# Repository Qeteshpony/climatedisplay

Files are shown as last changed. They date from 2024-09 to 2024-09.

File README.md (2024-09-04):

# Climate Display



3D Render

[Hardware Documentation](https://qeteshpony.github.io/climatedisplay)

Complete overhaul of one of my earlier electronics projects! A display that is running here for years, back then made completely with THT components on a crude pcb. It shows the temperature and dew point for the room and outdoor sensors. 

I learned a lot about pcb design since then and was not happy with the look of the old device so I remade the whole device in a way that keeps the general look but a lot more fancy, moving everything but the display elements to the back of the board, adding a 3d-printed frame, replacing the barrel connector with USB-C and many more little things. 

The old version also had the digits of the displays backwards which didnt matter when I wrote the arduino script to run it. But now I want to use ESP-Home so they have to be wired correctly ;)

Every other dual-7-segment module is upside down so the decimal dot on the last digit in each row can be used as a ° symbol.

The original project was documented on my blog: https://electronics.qetesh.de/climate-display/

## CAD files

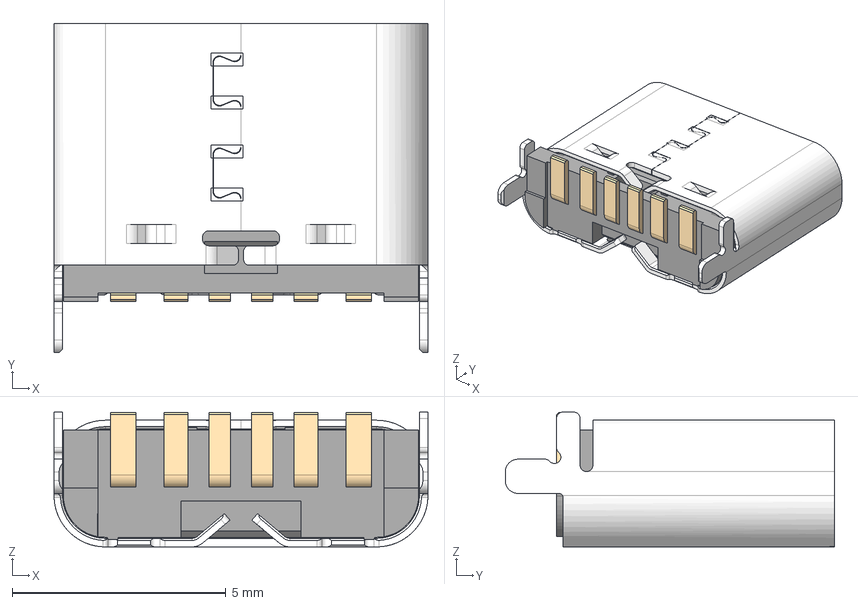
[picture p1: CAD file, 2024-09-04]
pcb/USB4130-GF-A_REVA/USB4130-GF-C.stp
8.74 x 7.70 x 3.15 mm

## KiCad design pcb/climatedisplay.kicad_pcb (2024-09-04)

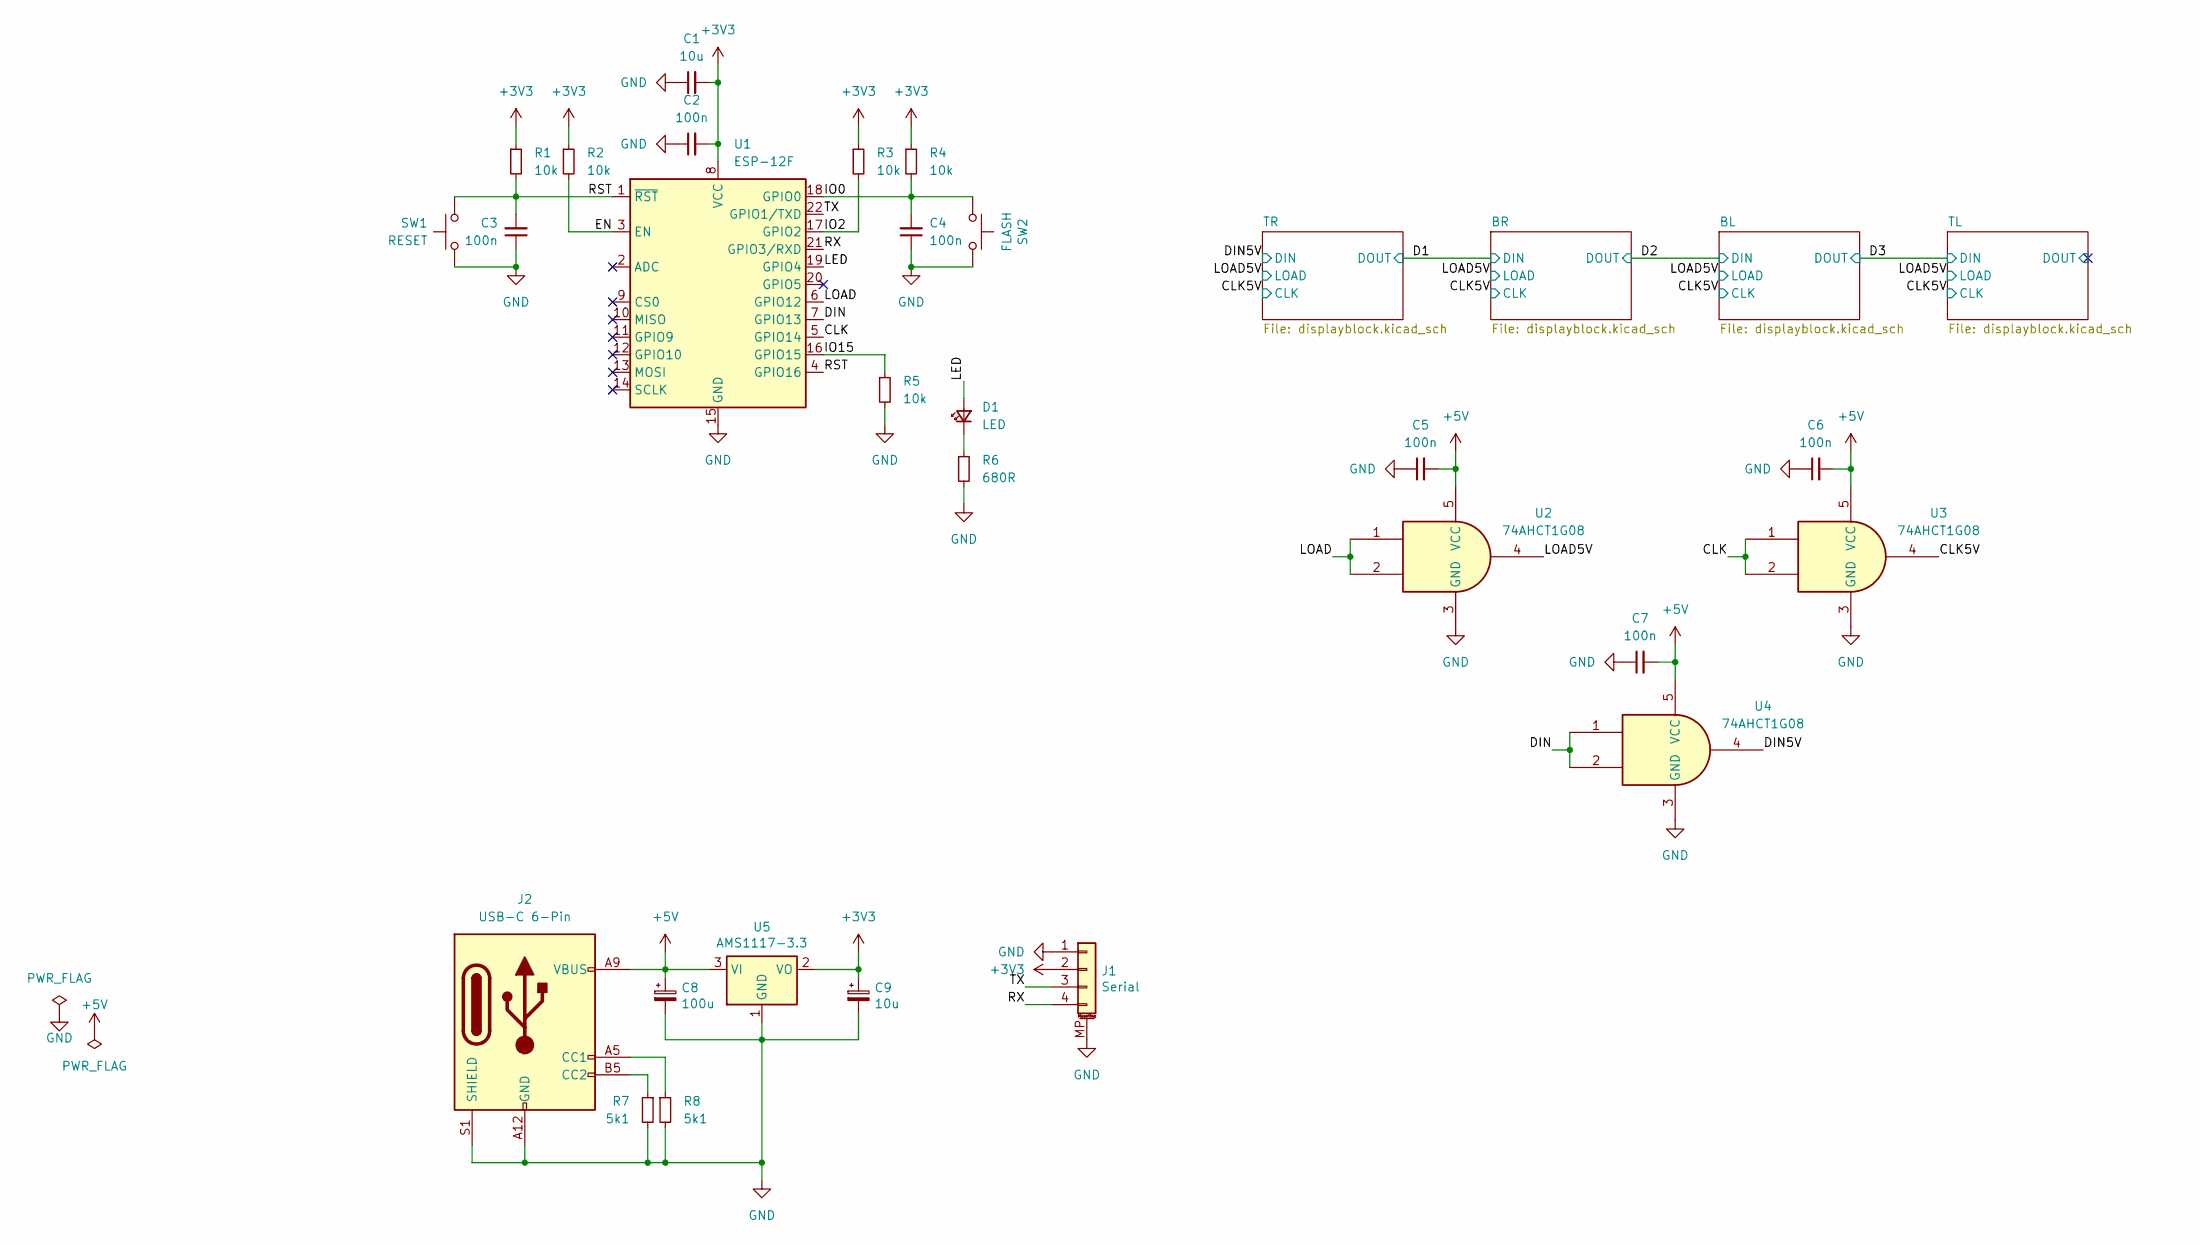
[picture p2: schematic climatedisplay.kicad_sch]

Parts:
C1: 10u; C_0402_1005Metric; LCSC C15525
C2, C3, C4, C5, C6, C7: 100n; C_0402_1005Metric; LCSC C1525
C8: 100u; CP_EIA-3528-21_Kemet-B; LCSC C16133
C9: 10u; CP_EIA-3216-18_Kemet-A; LCSC C7171
D1: LED; LED_0603_1608Metric; LCSC C2286
J1: Serial; JST_PH_S4B-PH-SM4-TB_1x04-1MP_P2.00mm_Horizontal
J2: USB-C 6-Pin; GCT_USB4130-GF-A_REVA
R1, R2, R3, R4, R5: 10k; R_0402_1005Metric; LCSC C25744
R6: 680R; R_0402_1005Metric; LCSC C25130
R7, R8: 5k1; R_0402_1005Metric; LCSC C25905
SW1: RESET; SW_Push_1P1T_XKB_TS-1187A; LCSC C318884
SW2: FLASH; SW_Push_1P1T_XKB_TS-1187A; LCSC C318884
U1: ESP-12F; ESP-12E
U2, U3, U4: 74AHCT1G08; SOT-353_SC-70-5; LCSC C455047
U5: AMS1117-3.3; SOT-223-3_TabPin2; LCSC C6186

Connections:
+3V3: C1.2, C2.2, C9.1, J1.2, R1.1, R2.1, R3.1, R4.1, U1.8 (VCC), U5.2 (VO)
+5V: C5.2, C6.2, C7.2, C8.1, J2.A9 (VBUS), J2.B9 (VBUS), U2.5 (VCC), U3.5 (VCC), U4.5 (VCC), U5.3 (VI); also elsewhere on the board
/CLK: U1.5 (GPIO14), U3.1, U3.2
/CLK5V: U3.4; also elsewhere on the board
/DIN: U1.7 (GPIO13), U4.1, U4.2
/DIN5V: U4.4; also elsewhere on the board
/EN: R2.2, U1.3 (EN)
/IO0: C4.2, R4.2, SW2.1, U1.18 (GPIO0)
/IO2: R3.2, U1.17 (GPIO2)
/IO15: R5.1, U1.16 (GPIO15)
/LED: D1.2 (A), U1.19 (GPIO4)
/LOAD: U1.6 (GPIO12), U2.1, U2.2
/LOAD5V: U2.4; also elsewhere on the board
/RST: C3.2, R1.2, SW1.2, U1.1 (~RST), U1.4 (GPIO16)
/RX: J1.4, U1.21 (GPIO3/RXD)
/TX: J1.3, U1.22 (GPIO1/TXD)
GND: C1.1, C2.1, C3.1, C4.1, C5.1, C6.1, C7.1, C8.2, C9.2, J1.1, J1.MP (MountPin), J2.A12 (GND), J2.B12 (GND), J2.S1 (SHIELD), R5.2, R6.2, R7.2, R8.2, SW1.1, SW2.2, U1.15 (GND), U2.3 (GND), U3.3 (GND), U4.3 (GND), U5.1 (GND); also elsewhere on the board
unnamed: D1.1 (K), R6.1
unnamed: J2.A5 (CC1), R8.1
unnamed: J2.B5 (CC2), R7.1

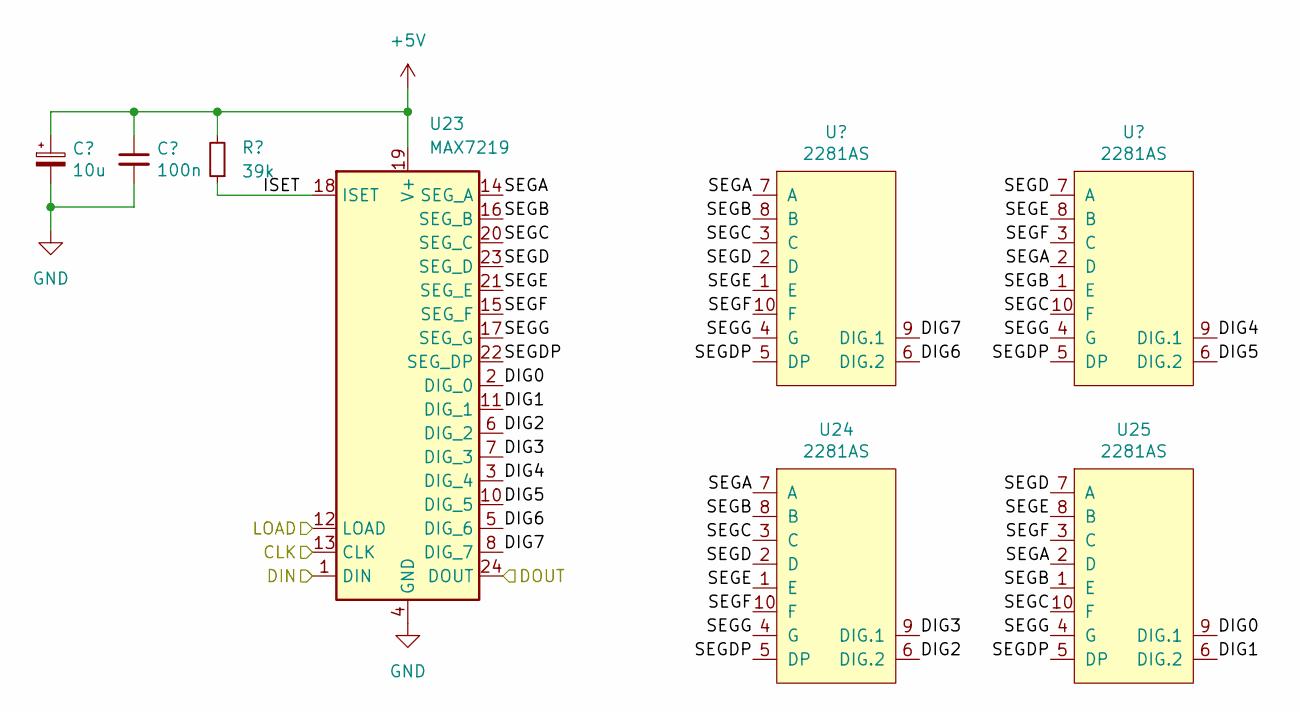
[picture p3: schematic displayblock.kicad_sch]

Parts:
C16: 10u; CP_EIA-3216-18_Kemet-A; LCSC C7171
C17: 100n; C_0402_1005Metric; LCSC C1525
R12: 39k; R_0402_1005Metric; LCSC C25783
U21, U22, U24, U25: 2281AS; 2281AS_BS
U23: MAX7219; SOP-24_7.5x15.4mm_P1.27mm; LCSC C9964

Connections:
+5V: C16.1, C17.1, R12.2, U23.19 (V+); also elsewhere on the board
/CLK5V: U23.13 (CLK); also elsewhere on the board
/D3: U23.1 (DIN); also elsewhere on the board
/LOAD5V: U23.12 (LOAD); also elsewhere on the board
/TL/DIG0: U23.2 (DIG_0), U25.9 (DIG.1)
/TL/DIG1: U23.11 (DIG_1), U25.6 (DIG.2)
/TL/DIG2: U23.6 (DIG_2), U24.6 (DIG.2)
/TL/DIG3: U23.7 (DIG_3), U24.9 (DIG.1)
/TL/DIG4: U22.9 (DIG.1), U23.3 (DIG_4)
/TL/DIG5: U22.6 (DIG.2), U23.10 (DIG_5)
/TL/DIG6: U21.6 (DIG.2), U23.5 (DIG_6)
/TL/DIG7: U21.9 (DIG.1), U23.8 (DIG_7)
/TL/DOUT: U23.24 (DOUT)
/TL/ISET: R12.1, U23.18 (ISET)
/TL/SEGA: U21.7 (A), U22.2 (D), U23.14 (SEG_A), U24.7 (A), U25.2 (D)
/TL/SEGB: U21.8 (B), U22.1 (E), U23.16 (SEG_B), U24.8 (B), U25.1 (E)
/TL/SEGC: U21.3 (C), U22.10 (F), U23.20 (SEG_C), U24.3 (C), U25.10 (F)
/TL/SEGD: U21.2 (D), U22.7 (A), U23.23 (SEG_D), U24.2 (D), U25.7 (A)
/TL/SEGDP: U21.5 (DP), U22.5 (DP), U23.22 (SEG_DP), U24.5 (DP), U25.5 (DP)
/TL/SEGE: U21.1 (E), U22.8 (B), U23.21 (SEG_E), U24.1 (E), U25.8 (B)
/TL/SEGF: U21.10 (F), U22.3 (C), U23.15 (SEG_F), U24.10 (F), U25.3 (C)
/TL/SEGG: U21.4 (G), U22.4 (G), U23.17 (SEG_G), U24.4 (G), U25.4 (G)
GND: C16.2, C17.2, U23.4 (GND), U23.9 (GND); also elsewhere on the board

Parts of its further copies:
C10, C12, C14: 10u; CP_EIA-3216-18_Kemet-A; LCSC C7171
C11, C13, C15: 100n; C_0402_1005Metric; LCSC C1525
R9, R10, R11: 39k; R_0402_1005Metric; LCSC C25783
U6, U7, U9, U10, U11, U12, U14, U15, U16, U17, U19, U20: 2281AS; 2281AS_BS
U8, U13, U18: MAX7219; SOP-24_7.5x15.4mm_P1.27mm; LCSC C9964

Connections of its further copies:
+5V: C10.1, C11.1, C12.1, C13.1, C14.1, C15.1, R9.2, R10.2, R11.2, U8.19 (V+), U13.19 (V+), U18.19 (V+); also elsewhere on the board
/BL/DIG0: U18.2 (DIG_0), U20.9 (DIG.1)
/BL/DIG1: U18.11 (DIG_1), U20.6 (DIG.2)
/BL/DIG2: U18.6 (DIG_2), U19.6 (DIG.2)
/BL/DIG3: U18.7 (DIG_3), U19.9 (DIG.1)
/BL/DIG4: U17.9 (DIG.1), U18.3 (DIG_4)
/BL/DIG5: U17.6 (DIG.2), U18.10 (DIG_5)
/BL/DIG6: U16.6 (DIG.2), U18.5 (DIG_6)
/BL/DIG7: U16.9 (DIG.1), U18.8 (DIG_7)
/BL/ISET: R11.1, U18.18 (ISET)
/BL/SEGA: U16.7 (A), U17.2 (D), U18.14 (SEG_A), U19.7 (A), U20.2 (D)
/BL/SEGB: U16.8 (B), U17.1 (E), U18.16 (SEG_B), U19.8 (B), U20.1 (E)
/BL/SEGC: U16.3 (C), U17.10 (F), U18.20 (SEG_C), U19.3 (C), U20.10 (F)
/BL/SEGD: U16.2 (D), U17.7 (A), U18.23 (SEG_D), U19.2 (D), U20.7 (A)
/BL/SEGDP: U16.5 (DP), U17.5 (DP), U18.22 (SEG_DP), U19.5 (DP), U20.5 (DP)
/BL/SEGE: U16.1 (E), U17.8 (B), U18.21 (SEG_E), U19.1 (E), U20.8 (B)
/BL/SEGF: U16.10 (F), U17.3 (C), U18.15 (SEG_F), U19.10 (F), U20.3 (C)
/BL/SEGG: U16.4 (G), U17.4 (G), U18.17 (SEG_G), U19.4 (G), U20.4 (G)
/BR/DIG0: U13.2 (DIG_0), U15.9 (DIG.1)
/BR/DIG1: U13.11 (DIG_1), U15.6 (DIG.2)
/BR/DIG2: U13.6 (DIG_2), U14.6 (DIG.2)
/BR/DIG3: U13.7 (DIG_3), U14.9 (DIG.1)
/BR/DIG4: U12.9 (DIG.1), U13.3 (DIG_4)
/BR/DIG5: U12.6 (DIG.2), U13.10 (DIG_5)
/BR/DIG6: U11.6 (DIG.2), U13.5 (DIG_6)
/BR/DIG7: U11.9 (DIG.1), U13.8 (DIG_7)
/BR/ISET: R10.1, U13.18 (ISET)
/BR/SEGA: U11.7 (A), U12.2 (D), U13.14 (SEG_A), U14.7 (A), U15.2 (D)
/BR/SEGB: U11.8 (B), U12.1 (E), U13.16 (SEG_B), U14.8 (B), U15.1 (E)
/BR/SEGC: U11.3 (C), U12.10 (F), U13.20 (SEG_C), U14.3 (C), U15.10 (F)
/BR/SEGD: U11.2 (D), U12.7 (A), U13.23 (SEG_D), U14.2 (D), U15.7 (A)
/BR/SEGDP: U11.5 (DP), U12.5 (DP), U13.22 (SEG_DP), U14.5 (DP), U15.5 (DP)
/BR/SEGE: U11.1 (E), U12.8 (B), U13.21 (SEG_E), U14.1 (E), U15.8 (B)
/BR/SEGF: U11.10 (F), U12.3 (C), U13.15 (SEG_F), U14.10 (F), U15.3 (C)
/BR/SEGG: U11.4 (G), U12.4 (G), U13.17 (SEG_G), U14.4 (G), U15.4 (G)
/CLK5V: U8.13 (CLK), U13.13 (CLK), U18.13 (CLK); also elsewhere on the board
/D1: U8.24 (DOUT), U13.1 (DIN)
/D2: U13.24 (DOUT), U18.1 (DIN)
/D3: U18.24 (DOUT); also elsewhere on the board
/DIN5V: U8.1 (DIN); also elsewhere on the board
/LOAD5V: U8.12 (LOAD), U13.12 (LOAD), U18.12 (LOAD); also elsewhere on the board
/TR/DIG0: U8.2 (DIG_0), U10.9 (DIG.1)
/TR/DIG1: U8.11 (DIG_1), U10.6 (DIG.2)
/TR/DIG2: U8.6 (DIG_2), U9.6 (DIG.2)
/TR/DIG3: U8.7 (DIG_3), U9.9 (DIG.1)
/TR/DIG4: U7.9 (DIG.1), U8.3 (DIG_4)
/TR/DIG5: U7.6 (DIG.2), U8.10 (DIG_5)
/TR/DIG6: U6.6 (DIG.2), U8.5 (DIG_6)
/TR/DIG7: U6.9 (DIG.1), U8.8 (DIG_7)
/TR/ISET: R9.1, U8.18 (ISET)
/TR/SEGA: U6.7 (A), U7.2 (D), U8.14 (SEG_A), U9.7 (A), U10.2 (D)
/TR/SEGB: U6.8 (B), U7.1 (E), U8.16 (SEG_B), U9.8 (B), U10.1 (E)
/TR/SEGC: U6.3 (C), U7.10 (F), U8.20 (SEG_C), U9.3 (C), U10.10 (F)
/TR/SEGD: U6.2 (D), U7.7 (A), U8.23 (SEG_D), U9.2 (D), U10.7 (A)
/TR/SEGDP: U6.5 (DP), U7.5 (DP), U8.22 (SEG_DP), U9.5 (DP), U10.5 (DP)
/TR/SEGE: U6.1 (E), U7.8 (B), U8.21 (SEG_E), U9.1 (E), U10.8 (B)
/TR/SEGF: U6.10 (F), U7.3 (C), U8.15 (SEG_F), U9.10 (F), U10.3 (C)
/TR/SEGG: U6.4 (G), U7.4 (G), U8.17 (SEG_G), U9.4 (G), U10.4 (G)
GND: C10.2, C11.2, C12.2, C13.2, C14.2, C15.2, U8.4 (GND), U8.9 (GND), U13.4 (GND), U13.9 (GND), U18.4 (GND), U18.9 (GND); also elsewhere on the board

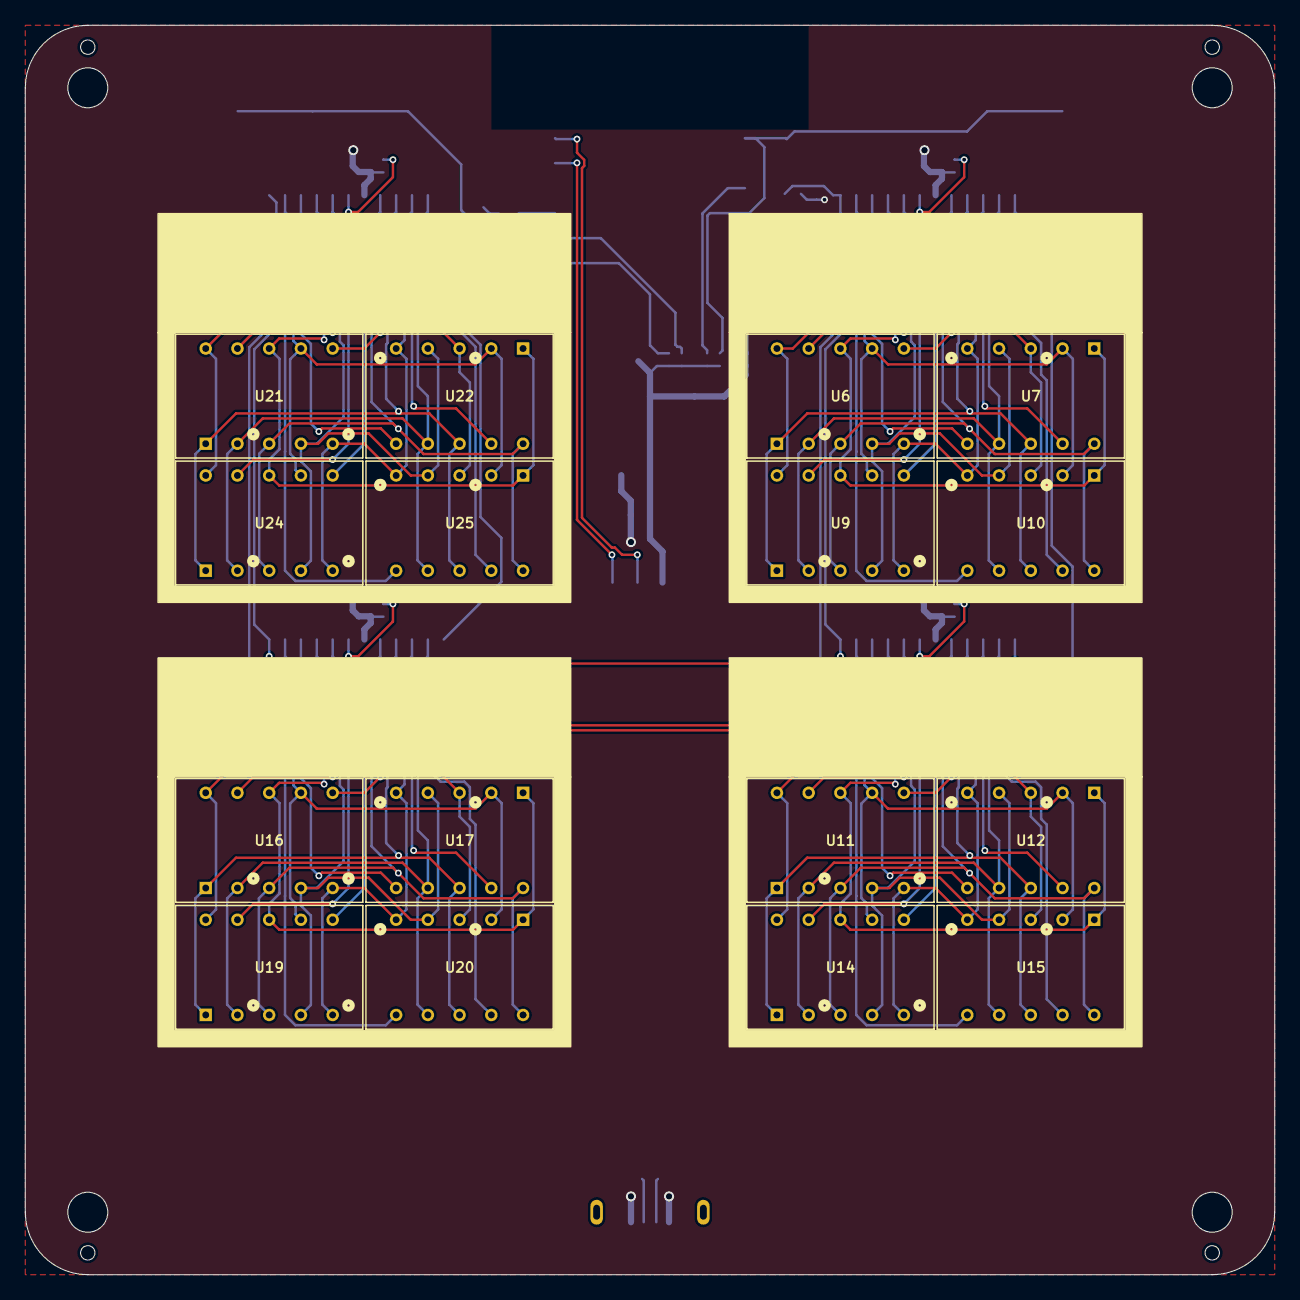
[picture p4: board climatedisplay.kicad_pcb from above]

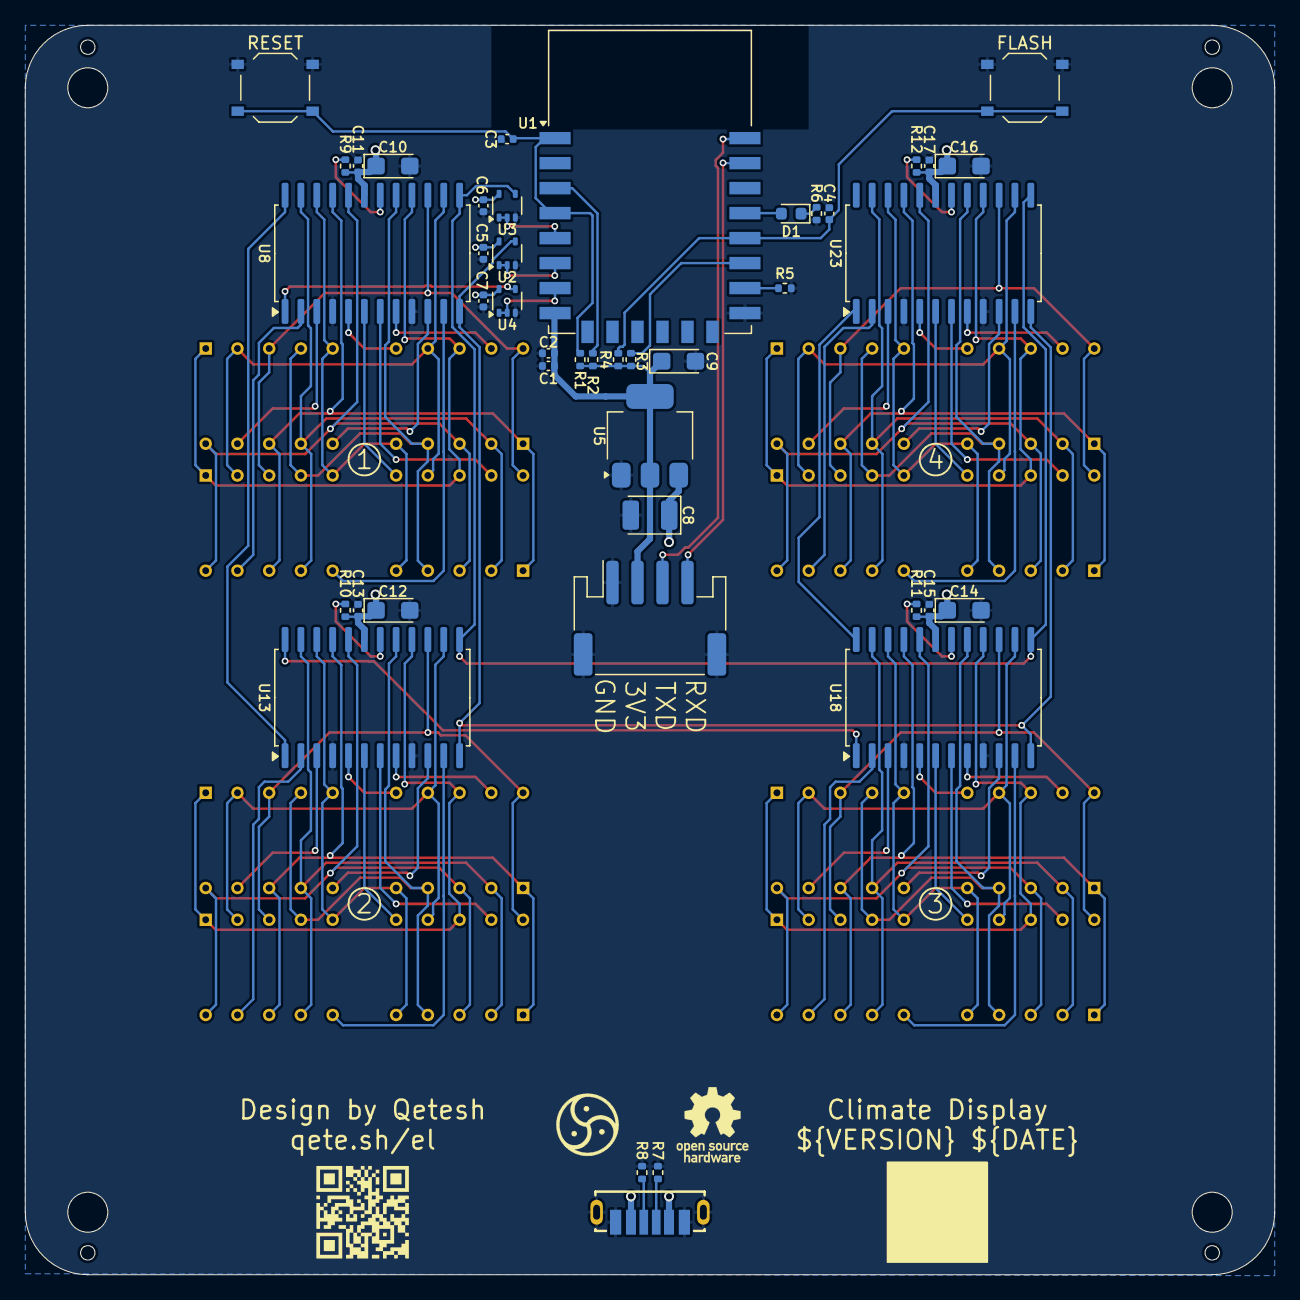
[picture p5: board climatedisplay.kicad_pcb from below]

Board: 2 copper layers, 100.0 x 100.0 mm, 59 parts (43 on the bottom side), 91 nets.

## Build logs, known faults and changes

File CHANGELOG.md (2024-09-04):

# Changelog

## [1.0.1](https://github.com/Qeteshpony/climatedisplay/compare/v1.0.0...v1.0.1) (2024-09-04)

### Bug Fixes

* footprints U2-U4 ([86ffc9e](https://github.com/Qeteshpony/climatedisplay/commit/86ffc9e7de1d0b95503fc52a2a1daa06c4d00a6f))

## 1.0.0 (2024-09-04)

### Features

* initial commit ([0d6bbaa](https://github.com/Qeteshpony/climatedisplay/commit/0d6bbaaf2273ea3c588e4f8e6eba57c5a675cbde))

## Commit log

2024-09-04 feat: initial commit
    [USB4130-GF-C.stp, climatedisplay.kicad_pcb, climatedisplay.kicad_sch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]
2024-09-04 fix: footprints U2-U4
    [climatedisplay.kicad_pcb, climatedisplay.kicad_sch]

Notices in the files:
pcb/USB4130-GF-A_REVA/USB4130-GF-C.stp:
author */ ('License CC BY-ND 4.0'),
